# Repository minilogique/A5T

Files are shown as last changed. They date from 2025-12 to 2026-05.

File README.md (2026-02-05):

# A5T

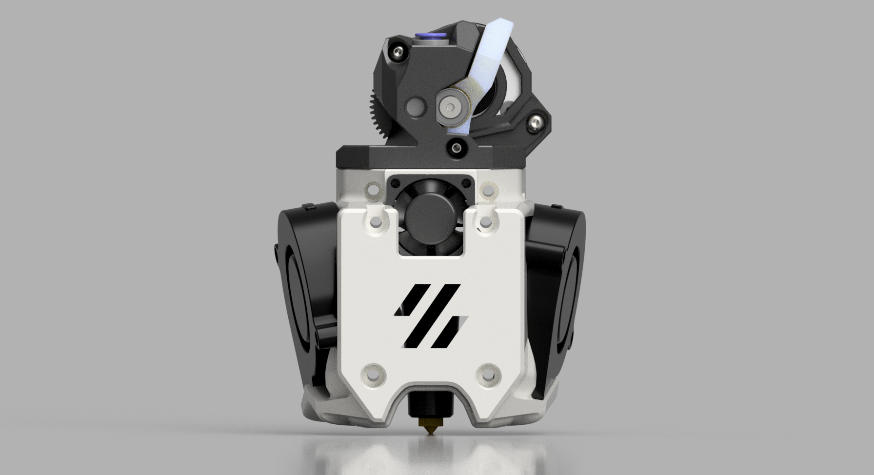
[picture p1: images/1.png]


+ **A5T is currently in testing; if you want to help out, ping the creator in Discord at @suzu00071 or join WKSuzuki Designs**

- This version is made for M3 flatheads. You need to drill and tap the radiator for M3 bolts. Reasoning behind this is that the M2.5 bolts that I got with the toolhead were soft as shi-, so to properly fix that I just upped the size. 
- Flatheads instead of normals for maximizing plastic above the radiator, extruder might not sit flush with the top of the shroud but instead on the flatheads themselves - heating the bolt a bit when tightening can alleviate that.
- 2510 fan is bolted directly into plastic with M3 bolts, do not manhandle it. 4 bolts is perfect, 2 is enough.
- Two topmost bolts are either normal hexhead or flat hex M3x30 compared to what A4T/A5T extruder adapter used to use. They are not needed, but add considerable amount of rigidity.
- Fully assembled weight without linear rail frame and extruder is 180grams.

___

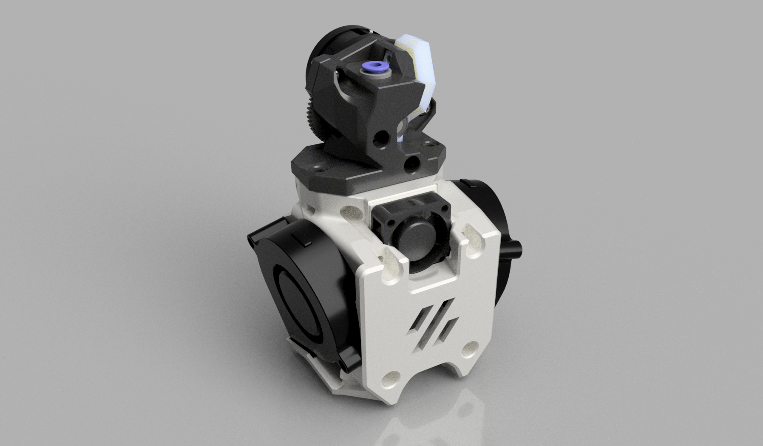
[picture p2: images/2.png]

___

> [!WARNING]
> A5T is not an easy print.

> [!NOTE]
> Use paint on supports for the duct enterances. Also made an M2.5 version but that has just abit over 3mm of plastic supporting the hotend. Use it at your own risk.

> [!WARNING]
> IF you are having issues with your toolhead mount not clearing the fan bolts, then use flatheads instead of normal bolts.

___

This work is licensed under <a href="https://creativecommons.org/licenses/by-nc-sa/4.0/">CC BY-NC-SA 4.0</a>

Support the creator.
<a href="https://ko-fi.com/suzuki00071">

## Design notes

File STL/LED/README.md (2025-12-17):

# LED Assembly

Print the diffuser parts in white/clear filament

Print the `Filter` and `Carrier` in black or other dark filament

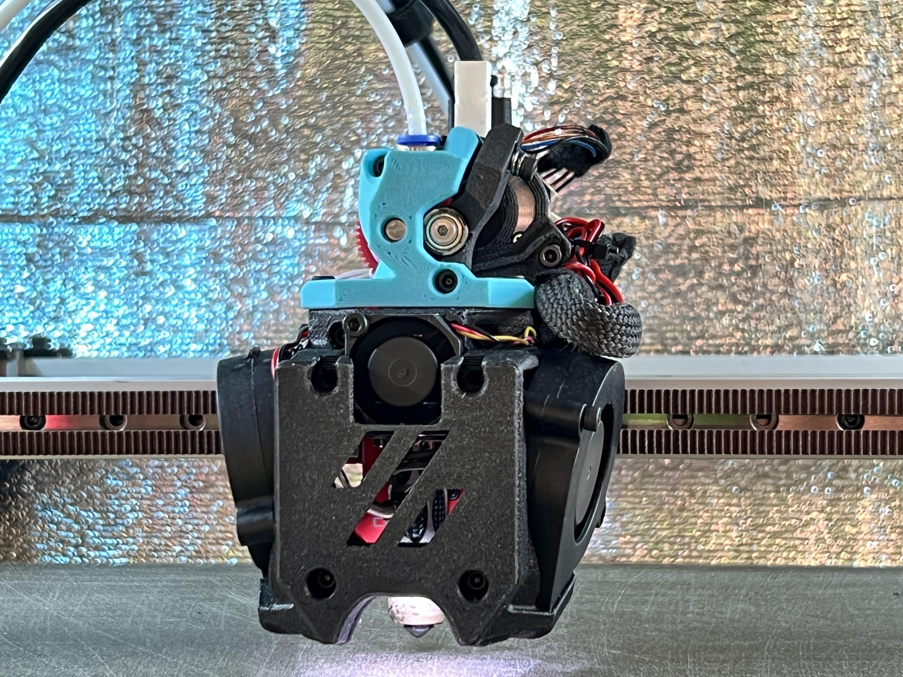
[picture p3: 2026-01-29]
images/real.JPG

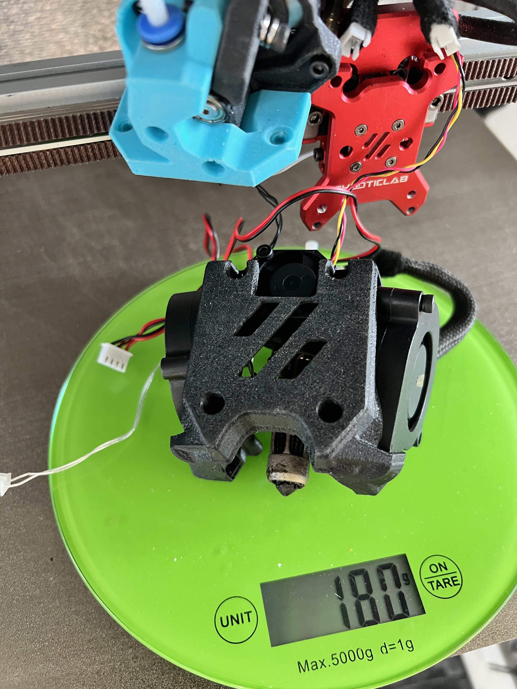
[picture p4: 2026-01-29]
images/weight.JPG

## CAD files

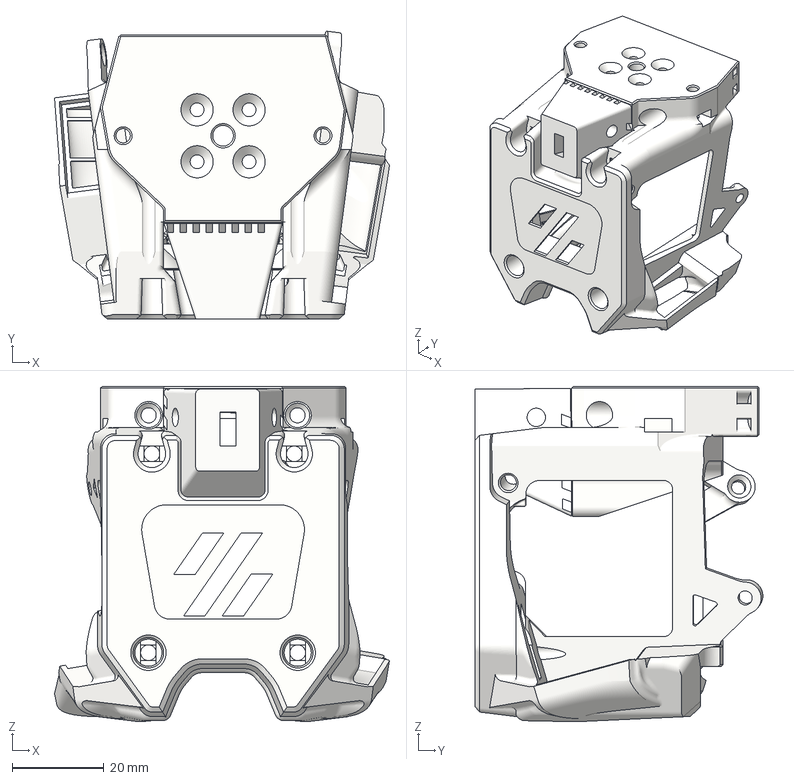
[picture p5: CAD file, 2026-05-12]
STL/Goliath A5T sherpa mini.3mf
72.9 x 62.6 x 73.0 mm
Goliath A5T cowl
faceplate
support (1)

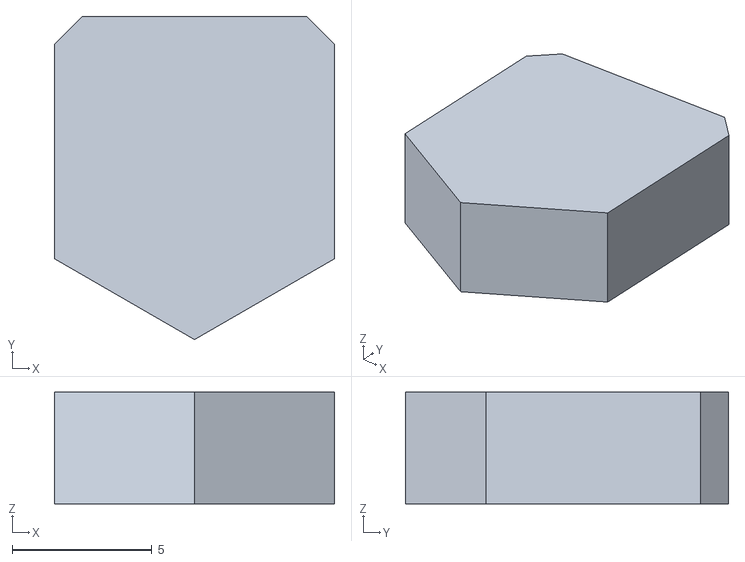
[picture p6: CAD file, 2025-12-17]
STL/LED/A5T-LED-diffuser-2.stl
10.0 x 11.5 x 4.00

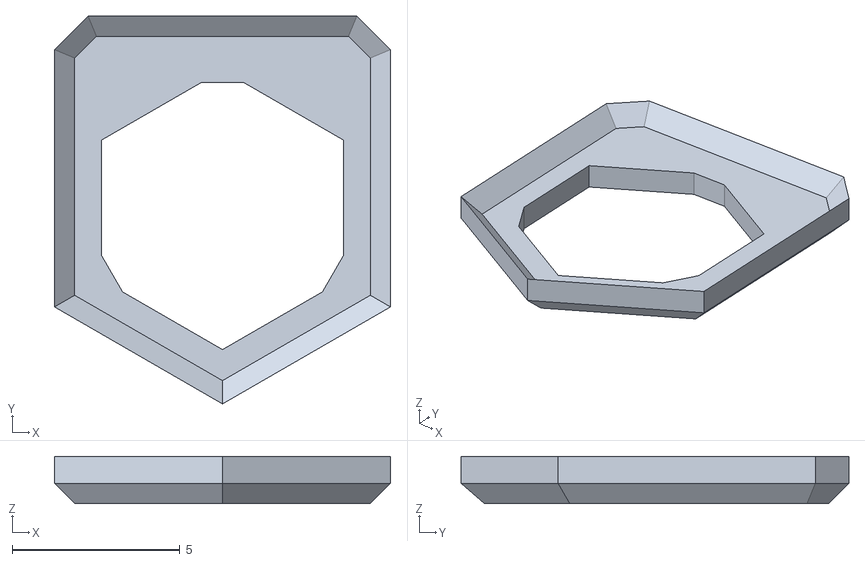
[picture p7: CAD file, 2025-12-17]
STL/LED/A5T-LED-Filter.stl
10.0 x 11.5 x 1.40

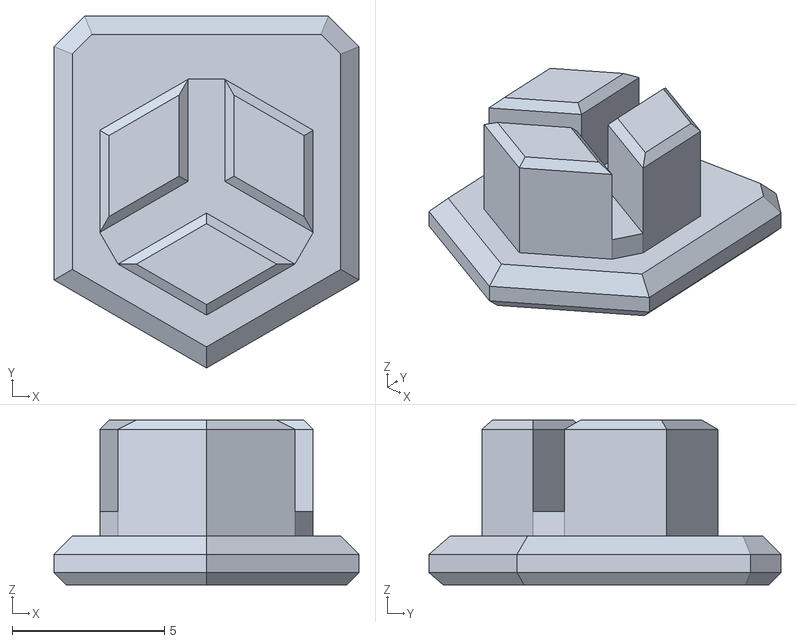
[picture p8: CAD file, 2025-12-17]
STL/LED/A5T-LED-diffuser-1.stl
10.0 x 11.5 x 5.40

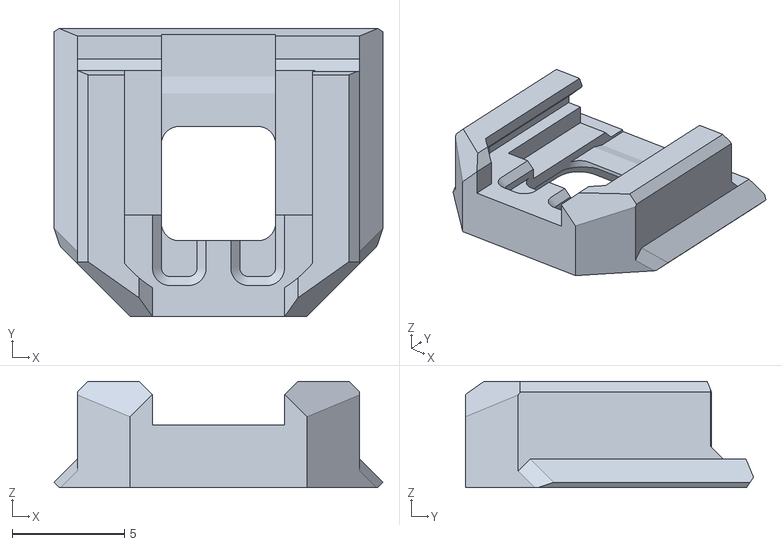
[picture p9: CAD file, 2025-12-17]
STL/LED/A5T-LED-Carrier.stl
14.7 x 12.9 x 4.75

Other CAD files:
STL/Goliath A5T Orbiter.3mf

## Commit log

2025-12-22 fixed screw holes on vindr tzv6
2026-01-26 some changes to change the changes
    [A5T-LED-Carrier.stl, A5T-LED-Filter.stl, A5T-LED-diffuser-1.stl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]
2026-01-29 Update A5T Goliath Air.3mf
    thinned and thickened fan mount ears so it fits better with CNC TAP
2026-02-05 new renders for new model; new 3D file
    changed the air duct to me more around the HE radiator; added a lip infront of the 2510 fan to not let it recirculate rising hot air; reduced the size of logo to reduce the leakage of hot air
2026-02-08 Update A5T Goliath Air.3mf
    [A5T Goliath Air.3mf]
2026-02-27 added Orbiter 2/2.5 support
    [Goliath A5T_orbiter.3mf, Goliath A5T_sherpa mini.3mf]
2026-04-22 minor changes
    [Goliath A5T Orbiter.3mf, Goliath A5T sherpa mini.3mf, Goliath A5T_orbiter.3mf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]
2026-04-27 minor tweaks
    [Goliath A5T Orbiter.3mf, Goliath A5T sherpa mini.3mf]
2026-05-12 removed M2.5 version; fixed the left side fan fitment issues;
    re-tap the threads to M3 if You haven't already - it has all the pros without the cons. made for M3x8 flatheads. buttonheads can be used but the extruder will hang a bit.
    [Goliath A5T Orbiter.3mf, Goliath A5T sherpa mini.3mf]
